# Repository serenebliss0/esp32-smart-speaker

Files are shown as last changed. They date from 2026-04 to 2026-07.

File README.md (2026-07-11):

# Wavelet
 
Wavelet is a family of ESP32-based smart speakers designed and developed as a modular audio platform. All three models share a common codebase and firmware philosophy, with features gated at compile time using preprocessor flags — one repository powers the entire family.
 
---
 
## The Wavelet Family
 
| Model | Position | Chip | Audio Config | Power | Networking |
|---|---|---|---|---|---|
| Wavelet Mini | Entry-level | ESP32-WROOM-32 | 1.0 Mono | 5V USB | None (BLE onboarding only) |
| Wavelet | Standard | ESP32-WROOM-32 | 2.0 True Stereo | 18650 Li-ion | BT A2DP |
| Wavelet Max | Flagship | ESP32-S3-DevKitC-1 | 2.1 Hi-Power | 12–24V DC wall | Full Wi-Fi (AP+STA) |
 
### 📻 Wavelet Mini — Entry-level
 
The Mini is the simplest and most portable member of the family. It functions as a compact mono Bluetooth speaker, USB-powered, with physical controls and a small display for clock faces and ambient UI. It keeps memory usage low by disabling Wi-Fi entirely and using NimBLE for lightweight BLE onboarding.
 
- **Audio:** Single MAX98357A configured for mono summation, driving one 2–2.5" speaker (3–5W)
- **Display:** Small screen for clock faces and system info (hardware in progress)
- **BLE:** NimBLE-based discovery and onboarding; saves config to NVS
- **Compile flag:** `WAVELET_MINI`
### 🔊 Wavelet — Standard
 
The standard Wavelet is the core consumer experience: a portable, battery-powered stereo Bluetooth speaker with physical controls and persistent settings.
 
- **Audio:** Two MAX98357A amplifiers in true stereo split (L/R via SD_MODE resistor configuration), driving two 3" speakers (5–10W each)
- **Power:** Single 18650 Li-ion cell with TP4056 + DW01 protection; voltage read via GPIO 35 through a resistive divider
- **Compile flag:** `WAVELET_REGULAR`
### 🧠 Wavelet Max — Flagship
 
The Max is a wall-powered smart home speaker focused on high output audio and full network integration. It moves beyond battery constraints to run a web dashboard, remote controls, and smart assistant features.
 
- **Audio:** MAX98357A as I2S pre-amplifier feeding a TPA3116D2 Class-D power amp, driving a 6.5" 600W coaxial car speaker driver
- **Power:** 12–24V 5A DC adapter; LM2596 buck converter steps down to 5V for the ESP32-S3
- **Networking:** Dual AP+STA Wi-Fi, ESPAsyncWebServer serving a browser dashboard from SPIFFS
- **MCU:** ESP32-S3 for dual-core performance, vector acceleration, and 8MB PSRAM
- **Compile flag:** `WAVELET_MAX`
---
 
## What this repository contains
 
This is a PlatformIO Arduino project targeting all three Wavelet models.
 
Current firmware features:
- Bluetooth audio sink playback via `ESP32-A2DP`
- Physical button controls (power, mode, previous, next, pause)
- Potentiometer-driven volume control with NVS persistence
- Wi-Fi dashboard with HTTP control API (Max only)
- Battery ADC telemetry with voltage divider mapping
- Startup and system feedback tones over I2S/buzzer
Also included:
- KiCad design files (`/esp32-smart-speaker-schema`)
- UI design iterations (`/webpage_iterations`)
- Dashboard screenshots (`/webpage-screenshots`)
---
 
## High-level architecture
 
Main entry point: `/src/main.cpp`
 
| Module | Location | Responsibility |
|---|---|---|
| `AudioManager` | `/src/audio/` | Buzzer tones, startup sounds, volume read + A2DP update, volume persistence |
| `Speaker` | `/src/core/` | Speaker modes and mode transition logic |
| `Buttons` | `/src/input/` | Button actions and long-press deep sleep |
| `WebServer` | `/src/web/` | Serves SPIFFS dashboard and HTTP control endpoints |
| `WiFiManager` | `/src/wifi/` | AP+STA networking and mDNS (`wavelet.local`) |
| `BLEManager` | `/src/ble/` | Battery percentage read and BLE characteristic updates |
| `PreferencesManager` | `/src/storage/` | NVS read/write for persisted settings |
 
Static web app files:
- `/data/index.html`
- `/data/styles.css`
- `/data/script.js`
---
 
## Speaker modes
 
Defined in `SpeakerMode` (`/src/core/Speaker.h`):
 
| Value | Mode |
|---|---|
| 0 | `BLUETOOTH` |
| 1 | `SMART_ASSISTANT` |
| 2 | `WIFI_STREAM` |
| 3 | `HEADPHONE_JACK` |
 
The mode button cycles through all four modes in order.
 
---
 
## Hardware and pin map
 
### Audio / I2S (shared)
 
| Signal | GPIO |
|---|---|
| I2S BCLK | 26 |
| I2S LRCLK | 25 |
| I2S DATA (DIN) | 4 |
| Buzzer | 27 |
| Volume potentiometer | 34 |
 
I2S peripheral: `I2S_NUM_0`
 
### Buttons
 
| Button | GPIO |
|---|---|
| Power | 23 |
| Mode | 21 |
| Previous | 19 |
| Next | 18 |
| Pause | 13 |
 
### Battery
 
| Signal | GPIO |
|---|---|
| ADC read | 35 |
 
---
 
## Build configuration
 
`/platformio.ini` defines three environments: `mini`, `regular`, and `max`.
 
Common settings across all environments:
- Platform: `espressif32`
- Framework: `arduino`
- Partitions: `min_spiffs.csv`
- 
| Environment | Board | Compile flag |
|---|---|---|
| `mini` | `esp32doit-devkit-v1` | `WAVELET_MINI` |
| `regular` | `esp32doit-devkit-v1` | `WAVELET_REGULAR` |
| `max` | `esp32s3box` (S3-DevKitC-1) | `WAVELET_MAX` |
 
---
 
## Getting started
 
### Prerequisites
- Python 3
- PlatformIO Core or PlatformIO IDE
- ESP32 USB drivers
### 1. Install PlatformIO
```bash
pip install platformio
```
 
### 2. Set Wi-Fi credentials
 
Open `/src/wifi/WiFiManager.cpp` and replace the placeholder SSID and password with your own before building or flashing. Do not skip this step.
 
### 3. Build firmware
```bash
cd <project_root>
python -m platformio run -e mini
```
 
Replace `mini` with `regular` or `max` as needed.
 
### 4. Upload firmware
```bash
python -m platformio run -e mini -t upload
```
 
### 5. Upload web assets to SPIFFS (Max only)
```bash
python -m platformio run -e max -t uploadfs
```
 
---
 
## Web dashboard and HTTP API
 
When Wi-Fi mode is active (Wavelet Max), the firmware hosts a browser dashboard and exposes HTTP control endpoints.
 
**Static routes:**
- `/` → redirects to `/index.html`
- `/index.html`, `/styles.css`, `/script.js`
**Control endpoints (GET):**
 
| Endpoint | Description |
|---|---|
| `/play` | Resume playback |
| `/pause` | Pause playback |
| `/next` | Skip to next track |
| `/previous` | Go to previous track |
| `/volume?v=<0..127>` | Set volume |
| `/mode?m=<0..3>` | Set speaker mode |
| `/battery` | Returns battery percent as plain integer (e.g. `78`) |
| `/nowplaying` | Returns `{ "track": "...", "artist": "..." }` |
 
Access the dashboard at `http://wavelet.local` once connected.
 
---
 
## Data persistence
 
NVS via `Preferences.h`:
 
| Namespace | Key | Value |
|---|---|---|
| `volume` | `volume` | Last set playback volume |
 
---
 
## Repository layout
 
```
/src                        Firmware source
/data                       SPIFFS web assets (HTML, CSS, JS)
/spk-sounds                 Source audio assets
/esp32-smart-speaker-schema KiCad design files
/webpage_iterations         UI concept history
/webpage-screenshots        Visual reference captures
/include /lib /test         Default PlatformIO folders
```

## Figma Designs

[Figma Designs](https://www.figma.com/design/wSVdh18lgMXjiUBImJqQXe/Wavelet-Mini--Max-UI-Design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)

Contains all the UI iterations across every model

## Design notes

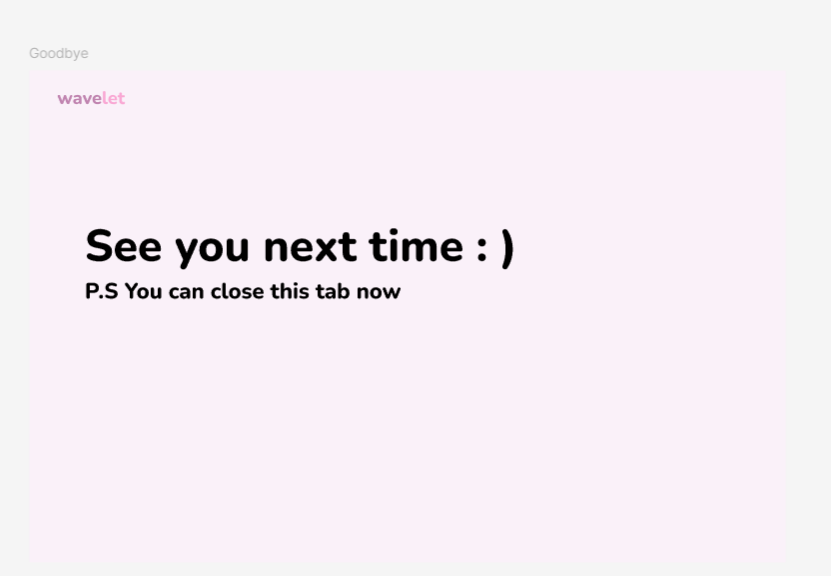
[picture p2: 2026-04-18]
webpage-screenshots/Screenshot 2026-03-15 223123.png

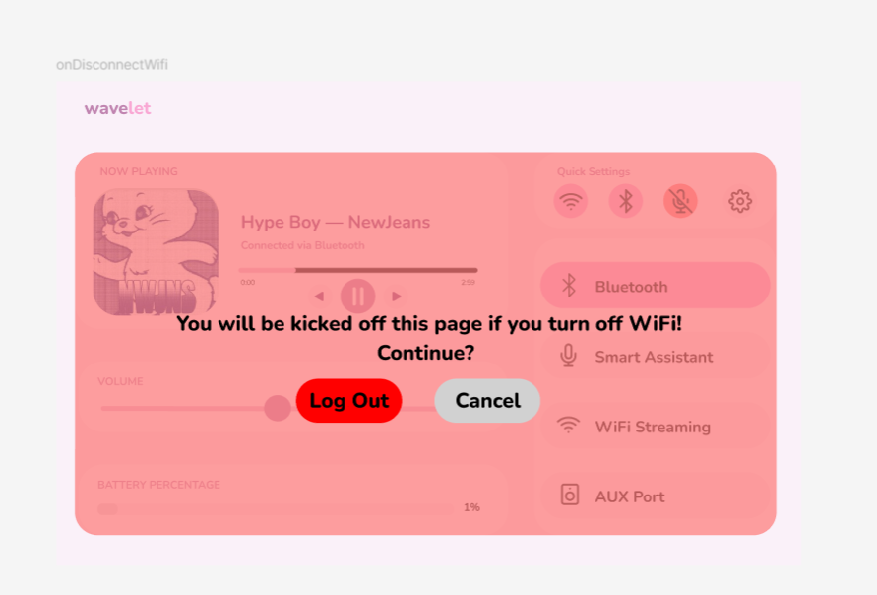
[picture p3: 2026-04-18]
webpage-screenshots/Screenshot 2026-03-15 223113.png

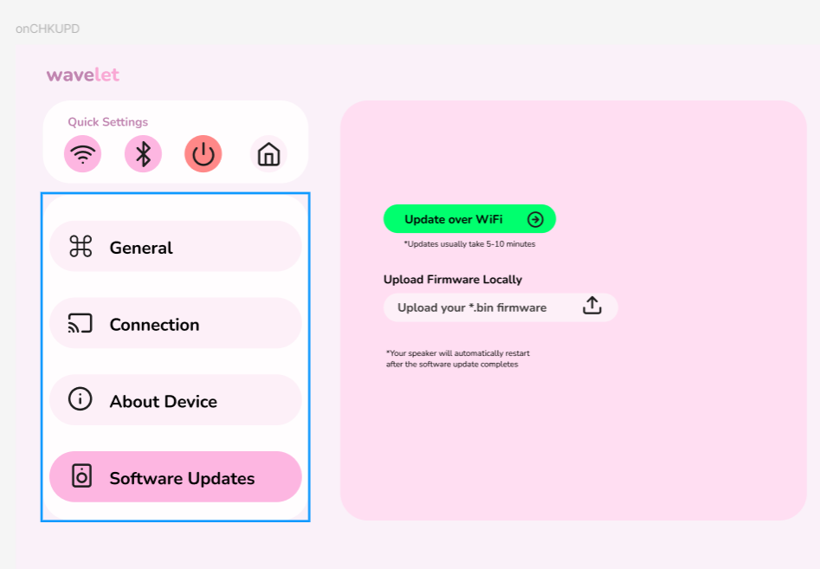
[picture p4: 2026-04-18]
webpage-screenshots/Screenshot 2026-03-17 135354.png

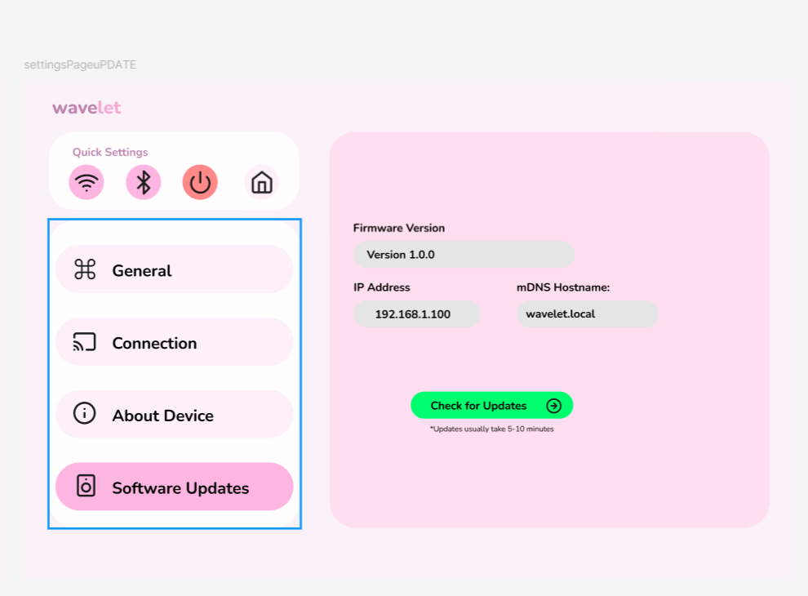
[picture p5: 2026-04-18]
webpage-screenshots/Screenshot 2026-03-17 135348.png

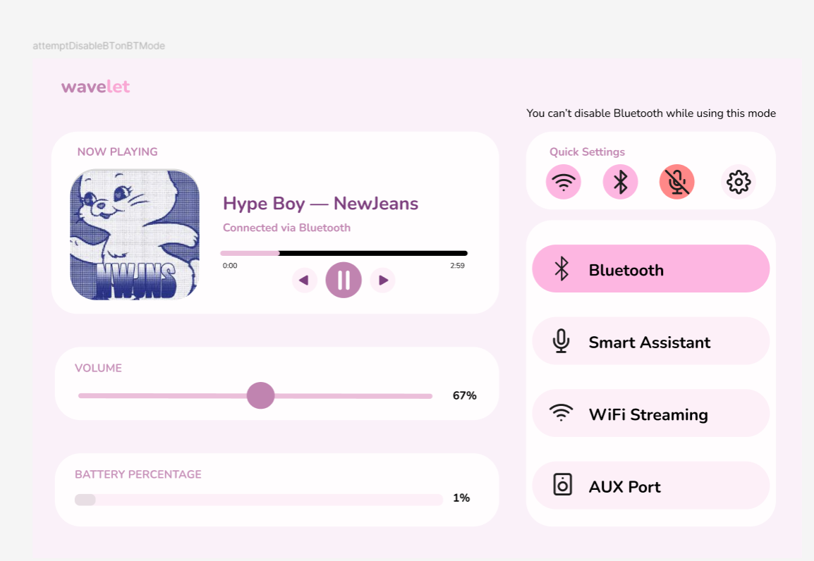
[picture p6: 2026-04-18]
webpage-screenshots/Screenshot 2026-03-15 223219.png

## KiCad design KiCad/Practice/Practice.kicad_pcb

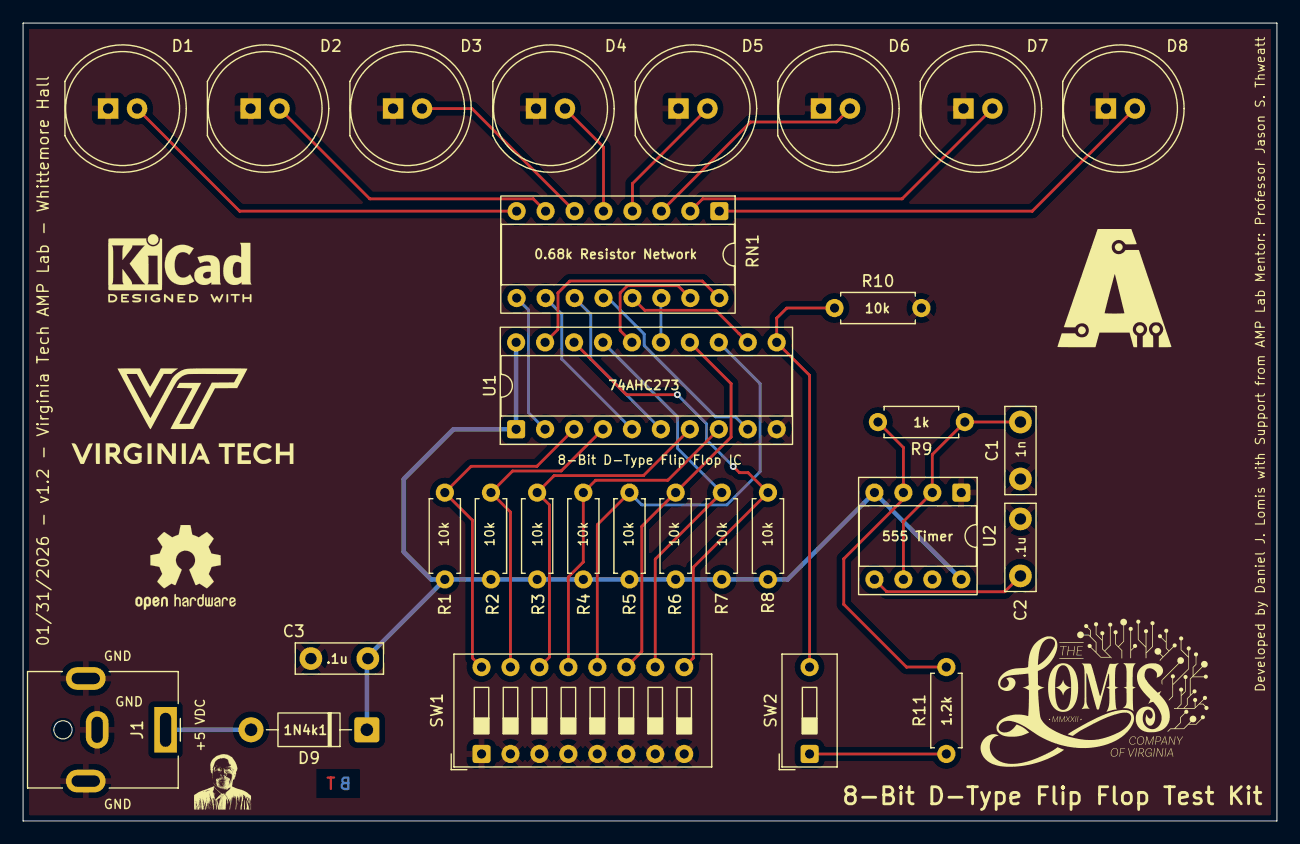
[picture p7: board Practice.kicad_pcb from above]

Board: 4 copper layers, 110.0 x 70.0 mm, 29 parts (0 on the bottom side), 32 nets.

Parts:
C1: 1n; C_Disc_D7.5mm_W2.5mm_P5.00mm
C2, C3: 100n; C_Disc_D7.5mm_W2.5mm_P5.00mm
D1, D2, D3, D4, D5, D6, D7, D8: LED; LED_D10.0mm
D9: 1N4001; D_DO-41_SOD81_P10.16mm_Horizontal
J1: Barrel_Jack_MountingPin; BarrelJack_CUI_PJ-063AH_Horizontal
R1, R2, R3, R4, R5, R6, R7, R8, R10: 10k; R_Axial_DIN0207_L6.3mm_D2.5mm_P7.62mm_Horizontal
R9: 1k; R_Axial_DIN0207_L6.3mm_D2.5mm_P7.62mm_Horizontal
R11: 1.2k; R_Axial_DIN0207_L6.3mm_D2.5mm_P7.62mm_Horizontal
RN1: R_Pack08; DIP-16_W7.62mm_Socket
SW1: SW_DIP_x08; SW_DIP_SPSTx08_Slide_9.78x22.5mm_W7.62mm_P2.54mm
SW2: SW_DIP_x01; SW_DIP_SPSTx01_Slide_9.78x4.72mm_W7.62mm_P2.54mm
U1: 74AHC273; DIP-20_W7.62mm_Socket
U2: ICM7555xP; DIP-8_W7.62mm_Socket

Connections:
+5V: C3.1, D9.1 (K), R1.1, R2.1, R3.1, R4.1, R5.1, R6.1, R7.1, R8.1, U1.1 (~Mr), U1.20 (VCC), U2.4 (R), U2.8 (VCC)
GND: C1.1, C2.2, C3.2, D1.1 (K), D2.1 (K), D3.1 (K), D4.1 (K), D5.1 (K), D6.1 (K), D7.1 (K), D8.1 (K), J1.2, J1.MP (MountPin), R10.2, SW1.1, SW1.2, SW1.3, SW1.4, SW1.5, SW1.6, SW1.7, SW1.8, U1.10 (GND), U2.1 (GND)
unnamed: D1.2 (A), RN1.8 (R8.1)
unnamed: D2.2 (A), RN1.7 (R7.1)
unnamed: D3.2 (A), RN1.6 (R6.1)
unnamed: D4.2 (A), RN1.5 (R5.1)
unnamed: D5.2 (A), RN1.4 (R4.1)
unnamed: D6.2 (A), RN1.3 (R3.1)
unnamed: D7.2 (A), RN1.2 (R2.1)
unnamed: D8.2 (A), RN1.1 (R1.1)
unnamed: D9.2 (A), J1.1
unnamed: R11.1, SW2.1
unnamed: RN1.16 (R1.2), U1.19 (Q7)
unnamed: RN1.15 (R2.2), U1.16 (Q6)
unnamed: RN1.14 (R3.2), U1.15 (Q5)
unnamed: RN1.13 (R4.2), U1.12 (Q4)
unnamed: RN1.12 (R5.2), U1.9 (Q3)
unnamed: RN1.11 (R6.2), U1.6 (Q2)
unnamed: RN1.10 (R7.2), U1.5 (Q1)
unnamed: RN1.9 (R8.2), U1.2 (Q0)
unnamed: R10.1, SW2.2, U1.11 (Cp)
unnamed: R1.2, SW1.16, U1.3 (D0)
unnamed: R2.2, SW1.15, U1.4 (D1)
unnamed: R3.2, SW1.14, U1.7 (D2)
unnamed: R4.2, SW1.13, U1.8 (D3)
unnamed: R5.2, SW1.12, U1.13 (D4)
unnamed: R6.2, SW1.11, U1.14 (D5)
unnamed: R7.2, SW1.10, U1.17 (D6)
unnamed: R8.2, SW1.9, U1.18 (D7)
unnamed: C2.1, U2.5 (CV)
unnamed: R9.2, R11.2, U2.3 (Q)
unnamed: C1.2, R9.1, U2.2 (TR), U2.6 (THR)

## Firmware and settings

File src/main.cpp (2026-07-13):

/*
 * Project Name: ESP32 Smart Speaker
 * Description: A smart speaker with Bluetooth, and WiFi capabilities
 * Author: Semire Ajayi
 * Date: 12-MAR-2026
 * 
 * Hardware:
 * - ESP32 DevKit V1
 * - MAX98357A I2S Amplifier
 * - 4ohm, 8-Watt Speaker 
 * - Passive Buzzer
 * - 5k-ohm Potentiometer
 * - 5x Push Buttons
 * 
 * Connections:
 * - DIN (MAX98357A)-> Pin 22
 * - BCLK (MAX98357A) -> Pin 26
 * - LRCLK (MAX98357A) -> Pin 25
 * - BUTTONS 1-5 -> Pins [23, 21, 19, 18, 13]
 * - BUZZER -> Pin 27
 * - POTENTIOMETER -> Pin 34
 * - BATTERY PIN -> Pin 35
 * 
 * 
 */

#include <Arduino.h>
#include "BluetoothA2DPSink.h"
#include <WiFi.h>
#include "driver/i2s.h"
#include <Preferences.h>

#include "audio/AudioManager.h"
#include "ble/BLEManager.h"
#include "core/Speaker.h"

#if defined(WAVELET_REGULAR)
#include "input/Buttons.h"
#endif

#include "storage/PreferencesManager.h"

#ifdef WAVELET_MAX
#include "web/WebServer.h"
#include "wifi/WiFiManager.h"
#endif

#ifdef WAVELET_MINI
#include "wifi/WiFiManager.h"
#include "spotify_controller/Spotify.h"
#include "screens/splash/splash.h"
#include "mini-ble/BLEManager.h"
#include "screens/qr_setup.h"
#endif

#include "Config.h"

Preferences prefs;
AudioManager audio(prefs);

BluetoothA2DPSink a2dp_sink;

// comment this line to disable debug
#define DEBUG

//uncomment this line to enable BatteryStats
#define BATTERIES_CONNECTED

#define FIRMWARE_VERSION "1.0.0"

#if defined(WAVELET_MINI) || defined(WAVELET_REGULAR)
#ifdef BATTERIES_CONNECTED
#define BATTERY_PIN 35
#endif
#endif

void setup() {

    #ifdef DEBUG
    Serial.begin(115200);
    #endif

    ledcSetup(0, 2000, 8);
    ledcAttachPin(Config::BUZZER, 0);

    //esp_bt_controller_mem_release(ESP_BT_MODE_BLE);
    /*
    WiFi.disconnect(true);
    WiFi.mode(WIFI_OFF);
    delay(100);
    */

    prefs.begin("app", false); // open once

    #if defined(WAVELET_MINI) || defined(WAVELET_REGULAR)

    pinMode(Config::BUZZER, OUTPUT);
    
    pinMode(Config::PWR_BUTTON, INPUT_PULLUP);
    pinMode(Config::MODE_BUTTON, INPUT_PULLUP);
    pinMode(Config::PREVIOUS_BUTTON, INPUT_PULLUP);
    pinMode(Config::NEXT_BUTTON, INPUT_PULLUP);
    pinMode(Config::PAUSE_BUTTON, INPUT_PULLUP);
    
    #endif

    //wavelet mini setup proc
    #ifdef WAVELET_MINI  
    Preferences prefs;
    prefs.begin("wavelet", true);
    bool setupDone = prefs.getBool("setup_done", false);
    prefs.end();

    // //debug only, negate logic in prod
    if (!setupDone) {
        //showSetupQR("WVL-2A4F9C", "strawberry_pink", lv_scr_act());
        beginSetupMode("max", "strawberry_pink");
        printQRToSerial(buildQRPayload("max", "pink"));
    }
    #endif

    #ifdef DEBUG
    String mac_addr = WiFi.macAddress();
    Serial.println(WiFi.macAddress());
    #endif
    
    //esp_bt_controller_mem_release(ESP_BT_MODE_BLE);

    i2s_pin_config_t my_pins = {
        .bck_io_num = 26,
        .ws_io_num = 25,
        .data_out_num = 4, //DIN
        .data_in_num = I2S_PIN_NO_CHANGE
    };

    a2dp_sink.set_pin_config(my_pins);
    a2dp_sink.set_on_connection_state_changed(on_connected);
    a2dp_sink.set_auto_reconnect(false);

    #ifdef WAVELET_MAX
    getSongMetadata(); //achieve song info for the web ui
    #endif

    #ifdef WAVELET_MINI
    a2dp_sink.start("Wavelet Mini");
    #endif

    #ifdef WAVELET_REGULAR
    a2dp_sink.start("Wavelet");
    #endif

    #ifdef WAVELET_MAX
    a2dp_sink.start("Wavelet Max");
    #endif

  
    audio.play_startup_sound();

    int rememberedVolume = readRememberedVolume();
    a2dp_sink.set_volume(rememberedVolume);
    //i2s_set_clk(I2S_NUM_0, 44100, I2S_BITS_PER_SAMPLE_16BIT, I2S_CHANNEL_STEREO);
    audio.buzz(1000,1000);

    #ifdef WAVELET_MAX
    connectWiFi();
    delay(5000);
    startWebServer();
    getSongMetadata();
    #endif
}

void loop() {
  String serial_input_args = Serial.readStringUntil('\n');
  serial_input_args.trim(); // remove newline
  audio.updateVolume();

  #if defined(WAVELET_REGULAR) || defined(WAVELET_MINI)
  #ifdef DEBUG
  int battery_level = readBatteryLevel();
  Serial.println(battery_level);
  #endif
  update_battery();
  #endif

  #ifdef WAVELET_REGULAR
  checkModeButton();
  handlePowerButton();
  handlePreviousButton();
  handleNextButton();
  #endif
  //MDNS.update();

  if (serial_input_args == "volume")
  {
    Serial.println(String(rememberedVolume) + "%");
  }
}

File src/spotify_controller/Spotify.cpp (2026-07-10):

#include <Arduino.h>
#include "wifi/WiFiManager.h"
#include "Spotify.h"

const char* SSID = "";
const char* PASSWORD = "";
const char* CLIENT_ID = "";
const char* CLIENT_SECRET = "";
const char* REFRESH_TOKEN = "";

// Create an instance of the Spotify class (optional: specify retry count)
Spotify sp(CLIENT_ID, CLIENT_SECRET, REFRESH_TOKEN);


const int PLAY_BUTTON = 23;
const int PREV_BUTTON = 21;
const int NXT_BUTTON = 19;

volatile bool play_buttonPressed = false;
volatile bool prev_buttonPressed = false;
volatile bool next_buttonPressed = false;


void IRAM_ATTR play_buttonISR() {
    play_buttonPressed = true;
}

void IRAM_ATTR prev_buttonISR() {
    prev_buttonPressed = true;
}

void IRAM_ATTR next_buttonISR() {
    next_buttonPressed = true;
}


void initialize() {
connectWiFi();

 // Optionally set custom scopes the available scopes are listed below
 // sp.set_scopes("user-read-playback-state user-modify-playback-state");

 sp.begin();
 while (!sp.is_auth()) {
     sp.handle_client(); // Required for receiving the authorization code
 }

 Serial.printf("Authenticated! Refresh token: %s\n", sp.get_user_tokens().refresh_token);

 pinMode(PLAY_BUTTON, INPUT_PULLUP);
 pinMode(PREV_BUTTON, INPUT_PULLUP);
pinMode(NXT_BUTTON, INPUT_PULLUP);

 attachInterrupt(
    digitalPinToInterrupt(PLAY_BUTTON),
    play_buttonISR,
    FALLING
 );

 attachInterrupt(
    digitalPinToInterrupt(PREV_BUTTON),
    prev_buttonISR,
    FALLING
 );

 attachInterrupt(
    digitalPinToInterrupt(NXT_BUTTON),
    next_buttonISR,
    FALLING
 );

}



String lastTrack = "";
String lastArtist = "";
bool lastPlaying = false;


void getCurrentlyPlaying() {
if(sp.is_playing() != lastPlaying ||
sp.current_track_name() != lastTrack || sp.current_artist_names() != lastArtist)
{
 lastTrack = sp.current_track_name();
 lastArtist = sp.current_artist_names();
 lastPlaying = sp.is_playing();

 #ifdef DEBUG
 Serial.println();
 Serial.println("==========");
 Serial.println(lastPlaying ? "▶ Playing" : "⏸ Paused");
 Serial.println(lastArtist);
 Serial.println(lastTrack);
 Serial.println("==========");
 #endif
}

}

void pauseCurrentlyPlaying() {

    if (sp.is_playing()) 
    {
        response res = sp.pause_playback();
        Serial.println(res.status_code);
    }
    else{
        response res = sp.start_a_users_playback();
    }

}

// void resumeCurrentlyPlaying() {
//     response res = sp.start_a_users_playback();
// }

void playNextSong() {
    response res = sp.skip_to_next();
}

void playPreviousSong() {
    response res = sp.skip_to_previous();
}

void setVolume(int volume_level) {
    response res = sp.set_volume(volume_level);
}

void seekToPosition(int position_level) {
    response res = sp.seek_to_position(position_level);
}

void enableShuffling() {
    response res = sp.toggle_shuffle(spotify_types::SHUFFLE_ON);
}

void disableShuffling() {
    response res = sp.toggle_shuffle(spotify_types::SHUFFLE_OFF);
}

void disableRepeat() {
    response res = sp.set_repeat_mode(spotify_types::REPEAT_OFF);
}

void enableRepeat() {
    response res = sp.set_repeat_mode(spotify_types::REPEAT_TRACK);
}

void repeatOne() {
    response res = sp.set_repeat_mode(spotify_types::REPEAT_CONTEXT);
}

void getAvailableDevices() {
Serial.print("Device ID: ");
Serial.println(sp.current_device_id());

response res = sp.get_available_devices();

print_response(res);
}

void getAlbumCover() {
    Serial.println(
        sp.get_current_album_image_url(0)
    );
}

void searchSong(const char* song_name) {
    response res =
sp.search_for_item(song_name, "song");
}

void getUserPlaylists() {
    response res = sp.get_current_users_playlists();
    print_response(res);
}

unsigned long lastUpdate = 0;

// void loop() {

//     if (millis() - lastUpdate >= 2000)
//     {
//         lastUpdate = millis();
//         getCurrentlyPlaying();
//     }
    
//     if (play_buttonPressed) {
//         play_buttonPressed = false;
//         pauseCurrentlyPlaying();
//         Serial.println("Button pressed!");
//     }

//     if (prev_buttonPressed) {
//         prev_buttonPressed = false;
//         playPreviousSong();
//         Serial.println("Button pressed!");
//     }

//     if (next_buttonPressed) {
//         next_buttonPressed = false;
//         playNextSong();
//         Serial.println("Button pressed!");
//     }


// }

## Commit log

2026-04-18 Added missing files to new repo
    [esp32-smart-speaker-schema.kicad_pcb, esp32-smart-speaker-schema.kicad_sch]
2026-04-18 Fixed gitignore
    [esp32-smart-speaker-schema.kicad_pcb, esp32-smart-speaker-schema.kicad_sch]
2026-06-18 Add audio and BLE management features
    - Implement AudioManager class for audio control including volume management and sound playback.
    - Create BLEManager for battery level monitoring and BLE characteristics.
    - Develop Speaker class to manage speaker modes and Bluetooth connections.
    - Introduce Buttons handling for power and track navigation.
    - Set up PreferencesManager for saving and retrieving volume settings.
    - Establish WebServer for serving files and handling HTTP requests for playback control and metadata.
    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
    [esp32-smart-speaker-schema.kicad_sch, wavelet_max.kicad_sch, wavelet_mini.kicad_sch]
2026-06-22 Fixed a few bugs for the Wavelet Regular and Max Refactored Codebase
    [esp32-smart-speaker-schema.kicad_sch, wavelet_max.kicad_sch, wavelet_mini.kicad_sch]
2026-06-26 Add Spotify controller and wavelet default image header
    - Implemented Spotify controller functionality in Spotify.cpp, including methods for playback control, volume adjustment, and device management.
    - Created Spotify.h to declare external variables and function prototypes for the Spotify controller.
    - Added wavelet_default.h header file for image declaration.
    [esp32-smart-speaker-schema.kicad_sch]
2026-07-10 Started building a wavelet companion app in Flutter
    Currently creating the app's onboarding process
2026-07-11 Finished part of the initial onboarding for the wavelet companion app
    - Added more functionality
    - Theme now syncs according to device on first launch
    - Implemented WiFi scan features
    - Created template files for the max and mini's unique pair process
2026-07-12 Implement QR code scanning and BLE device discovery for Wavelet Mini setup
